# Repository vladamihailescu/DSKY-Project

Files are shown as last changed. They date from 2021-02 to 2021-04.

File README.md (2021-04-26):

# DSKY-Project
My open source journey to building a functional, historically-accurate DSKY interface that can be used in simulation. 
 
## v1.0 Hardware (Completed)
 - Raspberry Pi 3B+ running VirtualAGC + driving the display & keyboard
 - Nextion 4.3" LCD HMI (NX4827T043_11) display
 - Alarm Panel PCB designed by Riley Rainey
 - Hand assembled keyboard using Cherry MX blue key switches & Arduino UNO in USB HID mode
 - 3D Printed shell components made from models created/modified by Riley Rainey/Manoel DaSilva from original MIT drawings or myself

## v1.5 Hardware (In Progress)
 - Raspberry Pi 3B+ running VirtualAGC + driving the display & keyboard
 - Nextion 4.3" LCD HMI (NX4827T043_11) display
 - Alarm Panel PCB designed by Riley Rainey
 - Keyboard PCB designed by me with Cherry MX green key switches & LED backlighting
 - 3D Printed shell components made from models created/modified by Riley Rainey/Manoel DaSilva from original MIT drawings or myself

## v2.0 Hardware (Planned)
 - Raspberry Pi 3B+ running VirtualAGC + driving the display & keyboard
 - Custom EL display panel
 - Alarm Panel PCB designed by Riley Rainey
 - Keyboard switches assembled as per original spec using microswitches
 - 3D Printed shell components made from models created/modified by Riley Rainey from original MIT drawings or myself

## Software
 - Drivers for display, alarm panel & keyboard written in Python3
 - VirtualAGC project
 - Project Apollo - NASSP
 
## Setup
Raspberry Pi running VirtualAGC is driving the Nextion HMI, sending lamp instructions to the Alert board and reading keystrokes from Keyboard

## Task List
- 1.0
- [x] Build working GUI for HMI display
- [x] Driver for Nextion HMI display
- [x] Assemble alarm panel PCB
- [x] Driver for alarm panel
- [x] Assemble keyboard
- [x] Driver for keyboard
- [x] Update piDSKY2.py file
- [x] Test with VirtualAGC

- 1.5
- [x] Design & assemble a custom PCB for keyboard
- [ ] Improve code
- [ ] Refine GUI to more closely match original DSKY display
- [ ] Keyboard caps improvements
- [ ] Improve overall DSKY fit & finish & pave way to v2.0

## References
 [VirtualAGC Project](https://www.ibiblio.org/apollo/) - I am so thankful that this exists because it has been my dream to build my own DSKY ever since I first learned of the
 project\
 [Riley Rainey](https://github.com/rrainey) - His amazing work in designing the alert and keyboard PCBs, modeling the DSKY shell and inner components from original drawings gave
 me the opportunity to start this project\
 [Manoel DaSilva](https://github.com/ManoDaSilva) - He created the HMI file which I modified and adapted to my code and the Cherry MX keyswitch stems I used.\

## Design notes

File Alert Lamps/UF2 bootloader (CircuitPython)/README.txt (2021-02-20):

This UF2 bootloader is compiled for the Alarm Panel PCB designed by Riley Rainey (https://github.com/rrainey)
which uses the Microchip ATSAMD21E18A microcontroller.

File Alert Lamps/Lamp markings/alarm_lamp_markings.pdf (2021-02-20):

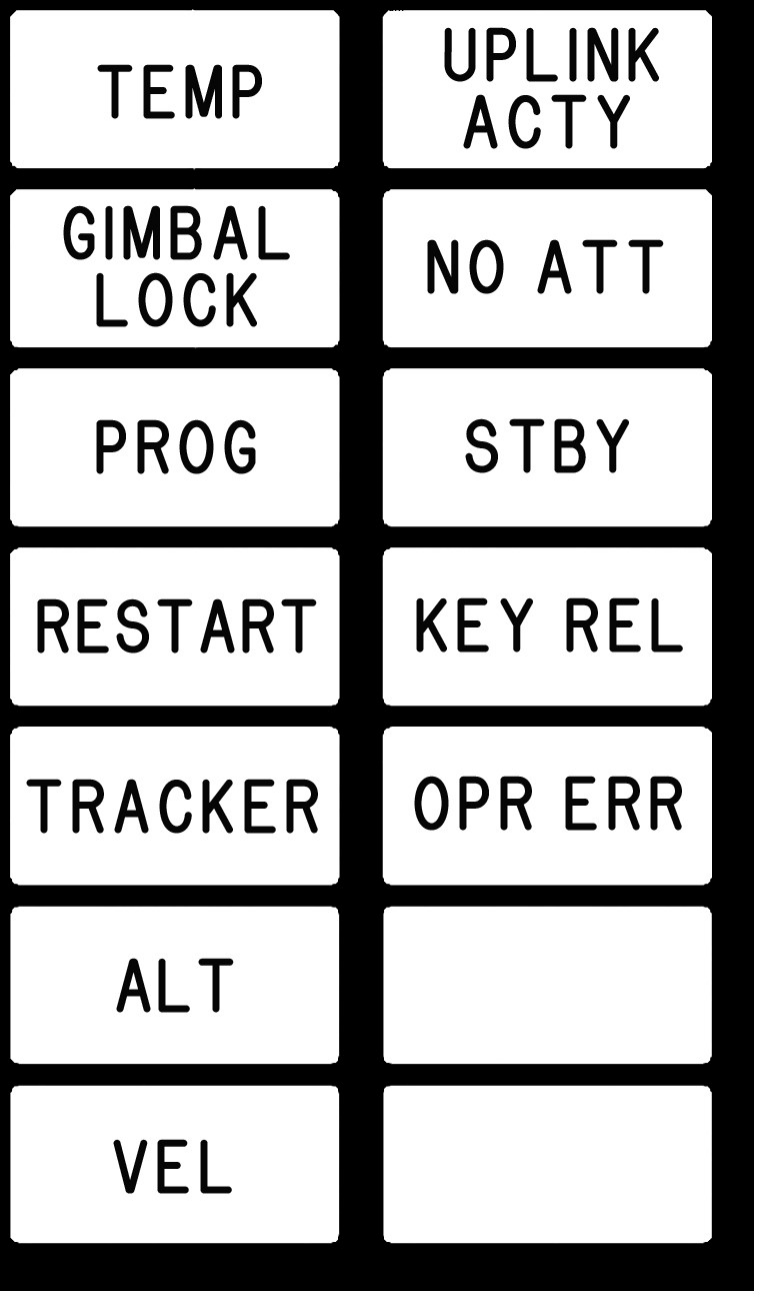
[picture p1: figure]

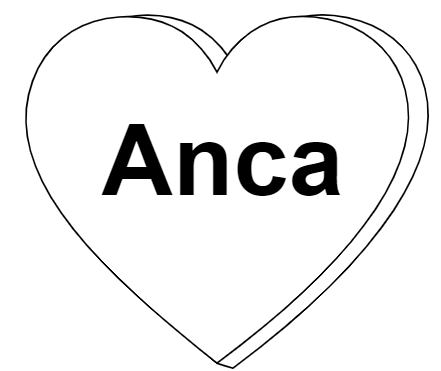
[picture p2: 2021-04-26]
Keyboard/PCB/DSKY_keyboard/anca_heart.png

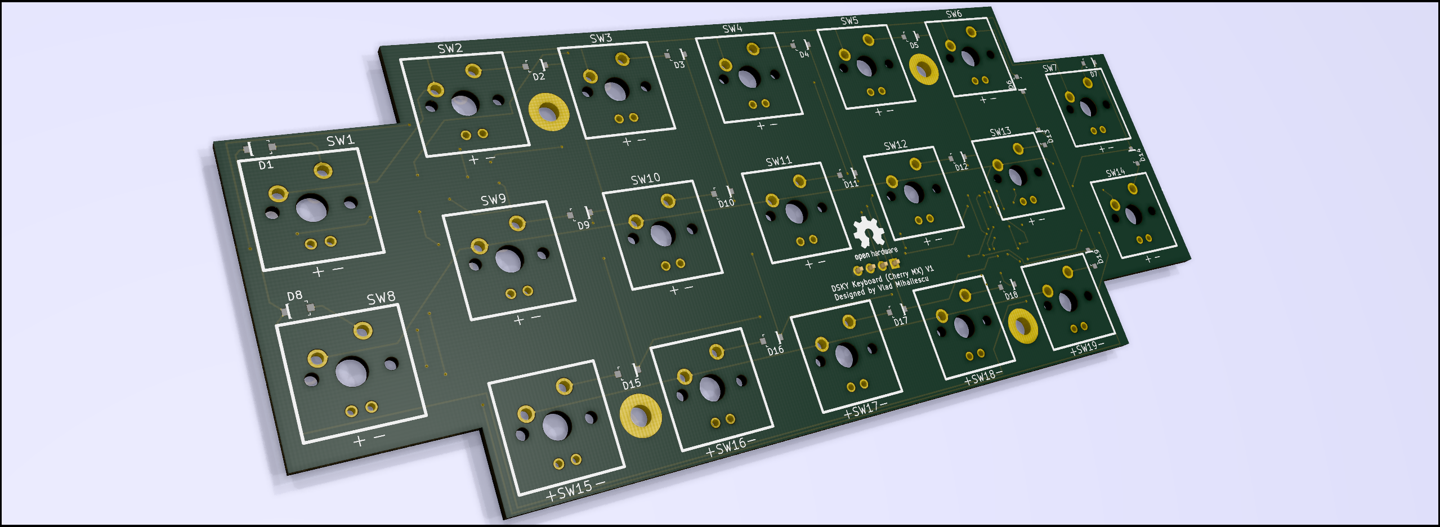
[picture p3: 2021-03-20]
Keyboard/PCB/DSKY_keyboard/DSKY_keyboard_Front.png

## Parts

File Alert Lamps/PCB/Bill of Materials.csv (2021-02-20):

Manufacturer Part Number | Manufacturer | Digi-Key Part Number | Packaging | Part Status | Quantity | Unit Price | Extended Price | Quantity Available | Mfg Std Lead Time | Description | RoHS Status | Lead Free Status | REACH Status
AQY232SZ | Panasonic Electric Works | 255-2690-1-ND | Cut Tape (CT) | Active | 15 | 4.481 | $67.21 | 7739 | 16 Weeks | SSR RELAY SPST-NO 500MA 0-60V | RoHS Compliant | Lead free | Not Available
CR0603-FX-1101ELF | Bourns Inc. | CR0603-FX-1101ELFCT-ND | Cut Tape (CT) | Active | 18 | 0.047 | $0.84 | 32367 | 14 Weeks | RES SMD 1.1K OHM 1% 1/10W 0603 | ROHS3 Compliant | Lead free | REACH Unaffected
1051330001 | Molex | WM9734CT-ND | Cut Tape (CT) | Active | 2 | 1.4 | $2.80 | 38785 | 13 Weeks | CONN RCPT USB2.0 MICRO B SMD | ROHS3 Compliant | Lead free | REACH Unaffected
AP2112K-3.3TRG1 | Diodes Incorporated | AP2112K-3.3TRG1DICT-ND | Cut Tape (CT) | Active | 4 | 0.72 | $2.88 | 0 | 30 Weeks | IC REG LINEAR 3.3V 600MA SOT25 | ROHS3 Compliant | Lead free | REACH Unaffected
7216 | Visual Communications Company - VCC | VCC7216-ND | Bulk | Not For New Designs | 45 | 1.046 | $47.07 | 2771 | 12 Weeks | LAMP INCAND T-1 WIRE TERM 5V | ROHS3 Compliant | Lead free | REACH Unaffected
CRGCQ0603F10K | TE Connectivity Passive Product | A129700CT-ND | Cut Tape (CT) | Active | 6 | 0.15 | $0.90 | 15229 | 19 Weeks | CRGCQ 0603 10K 1% | RoHS Compliant | Lead free | Not Available
CRGP0603F1K5 | TE Connectivity Passive Product | A130418CT-ND | Cut Tape (CT) | Active | 6 | 0.22 | $1.32 | 51357 | 19 Weeks | CRGP 0603 1K5 1% | RoHS Compliant | Lead free | Not Available
LT Q39G-Q1OO-25-1 | OSRAM Opto Semiconductors Inc. | 475-3442-1-ND | Cut Tape (CT) | Active | 2 | 0.57 | $1.14 | 46892 | 12 Weeks | LED GREEN DIFFUSED 0603 SMD | ROHS3 Compliant | Lead free | REACH Unaffected
LS Q976-NR-1 | OSRAM Opto Semiconductors Inc. | 475-2512-1-ND | Cut Tape (CT) | Active | 2 | 0.39 | $0.78 | 97330 | 12 Weeks | LED RED DIFFUSED 0603 SMD | ROHS3 Compliant | Lead free | REACH Unaffected
C0805C106K4PAC7210 | KEMET | 399-C0805C106K4PAC7210CT-ND | Cut Tape (CT) | Active | 6 | 0.28 | $1.68 | 7342 | 30 Weeks | CAP CER 10UF 16V X5R 0805 | ROHS3 Compliant | Not Available | REACH Unaffected
CL10A105KO8NNNC | Samsung Electro-Mechanics | 1276-1034-1-ND | Cut Tape (CT) | Active | 6 | 0.14 | $0.84 | 68766 | 22 Weeks | CAP CER 1UF 16V X5R 0603 | ROHS3 Compliant | Lead free | REACH Unaffected
KMR231NG LFS | C&K | CKN10246CT-ND | Cut Tape (CT) | Active | 2 | 0.8 | $1.60 | 14433 | 18 Weeks | SWITCH TACTILE SPST-NO 0.05A 32V | ROHS3 Compliant | Lead free | REACH Unaffected
ATSAMD21E18A-MU | Microchip Technology | ATSAMD21E18A-MU-ND | Tray | Active | 2 | 4.85 | $9.70 | 850 | 35 Weeks | IC MCU 32BIT 256KB FLASH 32QFN | ROHS3 Compliant | Lead free | REACH Unaffected
CR0603-FX-1501ELF | Bourns Inc. | 118-CR0603-FX-1501ELFCT-ND | Cut Tape (CT) | Active | 4 | 0.15 | $0.60 | 2301 | 14 Weeks | RES SMD 1.5K OHM 1% 1/10W 0603 | ROHS3 Compliant | Lead free | REACH Unaffected
This list includes plenty of spares and only adds a few extra dollars to the total price but worth it in case you mess up/lose parts.

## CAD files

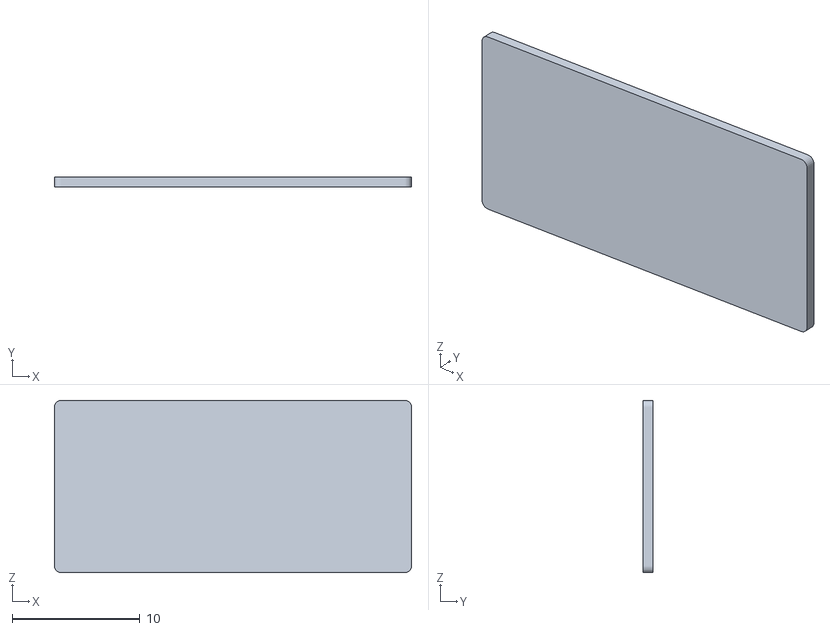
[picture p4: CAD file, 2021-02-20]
Alert Lamps/Lamp markings/Translucent inserts tree v4 v1.stl
27.9 x 0.762 x 13.5

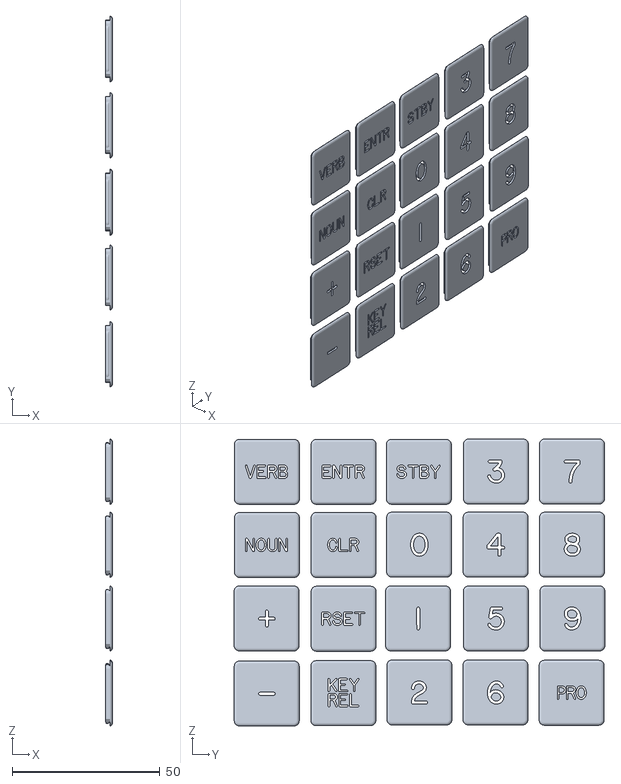
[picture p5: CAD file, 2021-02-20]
Keyboard/Keycaps/Markings/DSKY_KEYCAP v5.stl
2.29 x 125.3 x 97.0

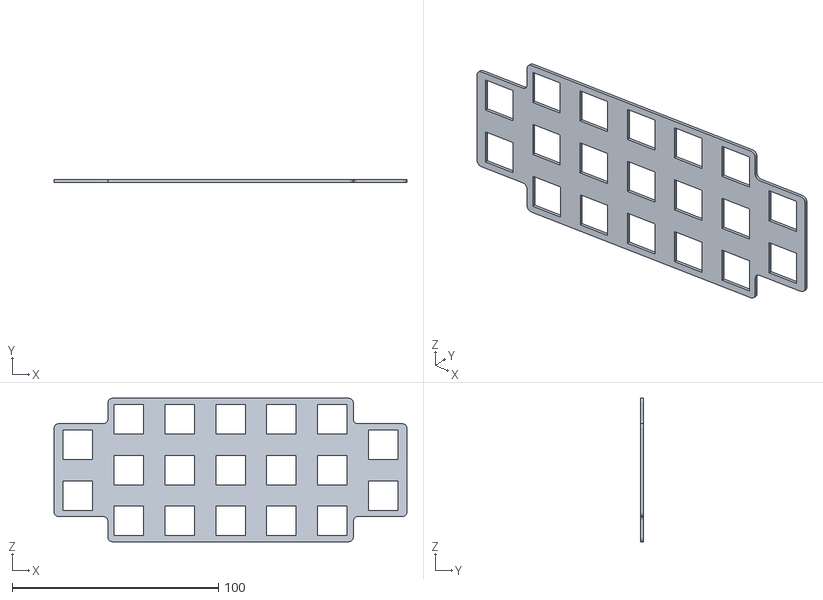
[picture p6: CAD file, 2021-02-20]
Keyboard/STL files/cherrymx_panel_mount.stl
171.0 x 1.30 x 69.6

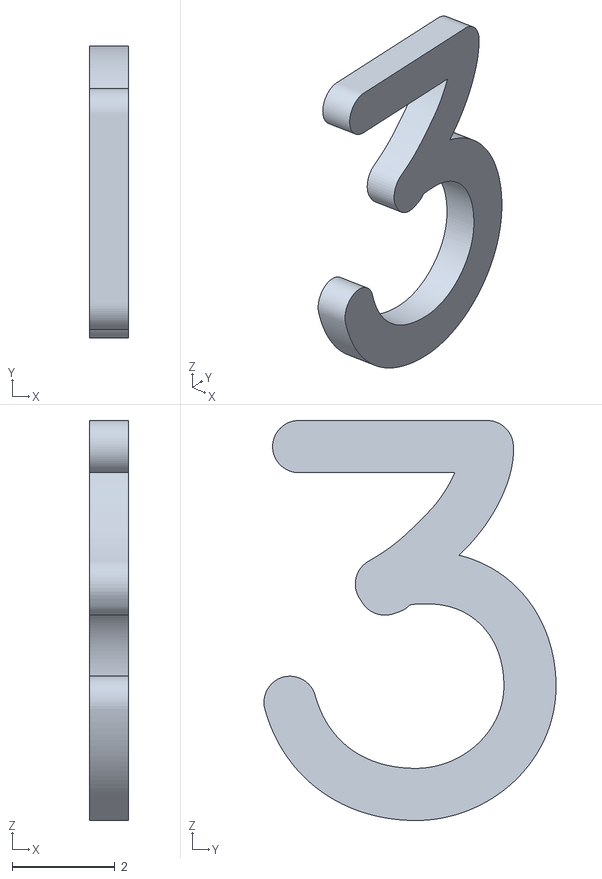
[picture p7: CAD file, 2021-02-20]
Keyboard/Keycaps/Markings/LP_3.stl
0.762 x 5.69 x 7.79

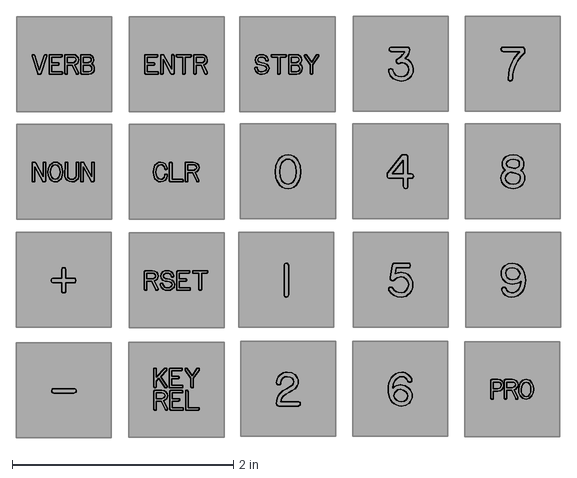
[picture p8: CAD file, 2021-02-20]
Keyboard/Keycaps/Markings/DSKY-keycaps.dxf
4.93 x 3.81 in

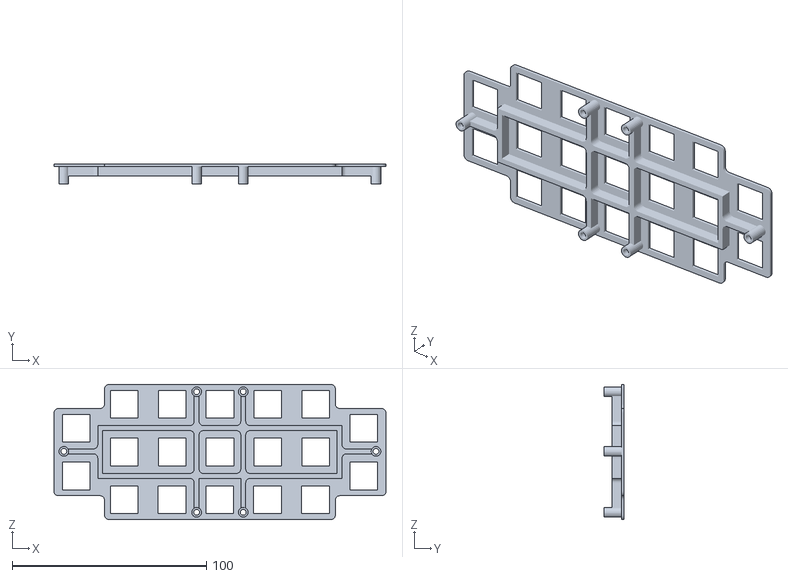
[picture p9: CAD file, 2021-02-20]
Keyboard/STL files/2004968E-ModFor3DPrint_VLAD v2.stl
171.0 x 10.3 x 69.6

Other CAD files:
Keyboard/CAD files/DSKY_keyboard_layout.dwg
Keyboard/Keycaps/Markings/verb.dxf
Alert Lamps/Lamp markings/Translucent inserts tree v4 v0.f3d

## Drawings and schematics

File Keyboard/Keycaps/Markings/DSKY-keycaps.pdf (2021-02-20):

3
7

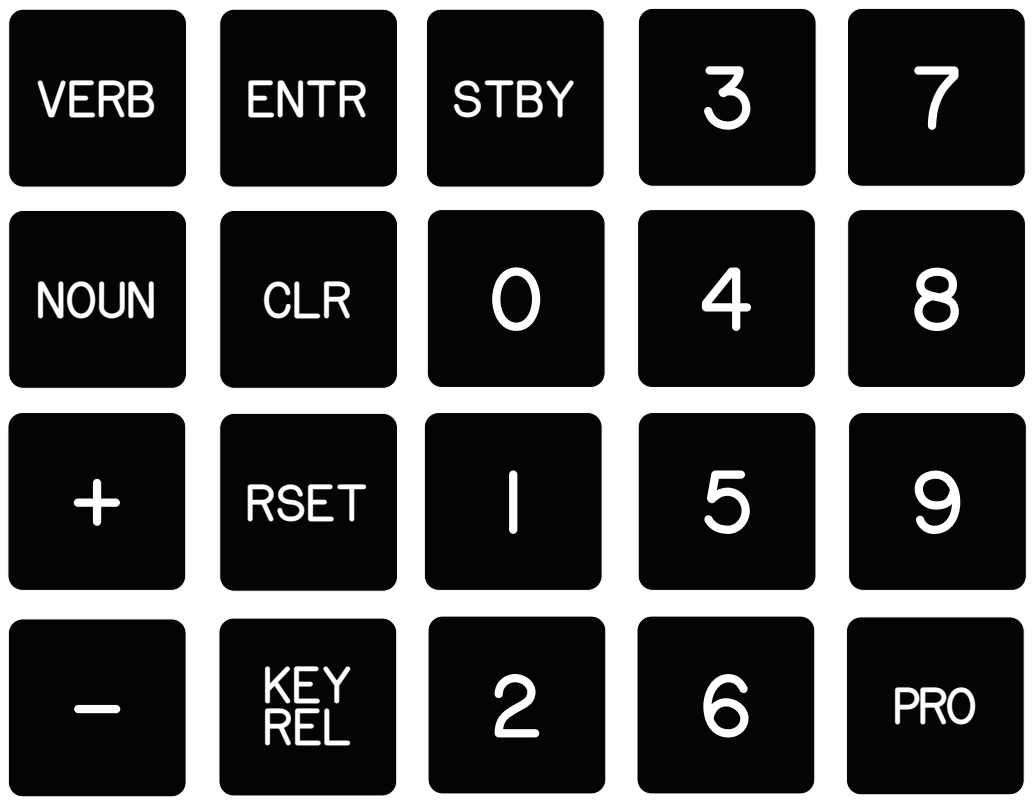
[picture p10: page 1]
VERB; NOUN; ENTR; CLR; RSET; KEY REL; STBY; PRO

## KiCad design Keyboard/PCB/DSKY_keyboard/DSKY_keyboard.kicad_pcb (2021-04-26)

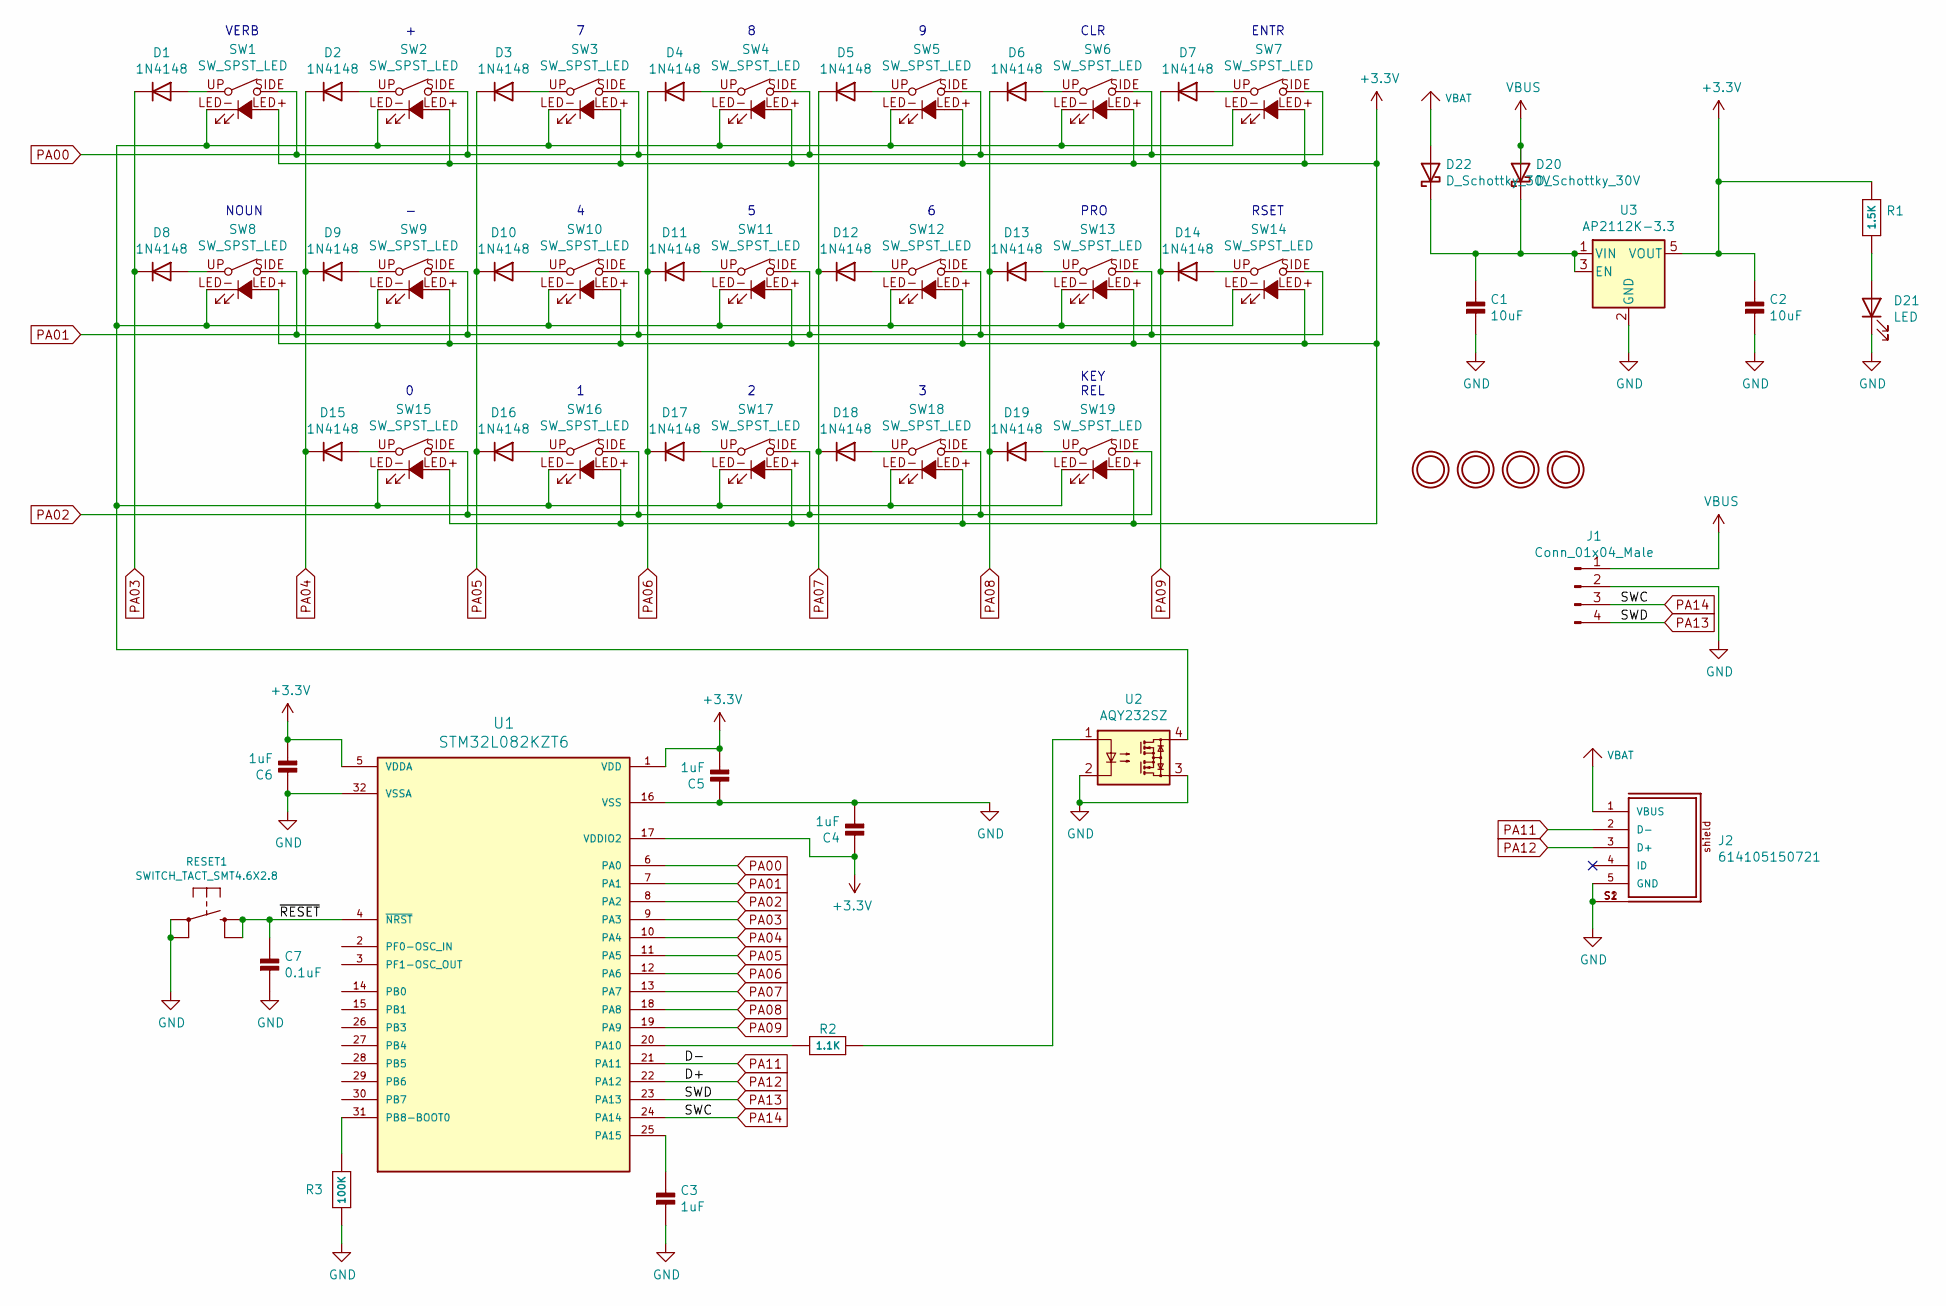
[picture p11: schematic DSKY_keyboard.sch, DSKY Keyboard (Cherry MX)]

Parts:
C1, C2: 10uF; 0805-NO
C3, C4, C5, C6: 1uF; 0603-NO
C7: 0.1uF; 0603-NO
D1, D2, D3, D4, D5, D6, D7, D8, D9, D10, D11, D12, D13, D14, D15, D16, D17, D18, D19: 1N4148; SOD-123
D20, D22: D_Schottky_30V; SOD-123FL
D21: LED; CHIPLED_0603_NOOUTLINE
J1: Conn_01x04_Male; PinHeader_1x04_P2.54mm_Horizontal
J2: 614105150721; PART-NUMBER 614105150721
J3, J4, J5, J6: MOUNTINGHOLE3.0; MOUNTINGHOLE_2.0_PLATED
R1: 1.5K; 0603-NO
R2: 1.1K; 0603-NO
R3: 100K; 0603-NO
RESET1: SWITCH_TACT_SMT4.6X2.8; BTN_KMR2_4.6X2.8
SW1, SW2, SW3, SW4, SW5, SW6, SW7, SW8, SW9, SW10, SW11, SW12, SW13, SW14, SW15, SW16, SW17, SW18, SW19: SW_SPST_LED; CHERRYMX-NN-LED
U1: STM32L082KZT6; STM32F042K6T6
U2: AQY232SZ; SO-4_4.4x4.3mm_P2.54mm
U3: AP2112K-3.3; SOT23-5

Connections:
+3V3: C2.1, C4.1, C5.2, C6.2, R1.1, SW1.LED+, SW2.LED+, SW3.LED+, SW4.LED+, SW5.LED+, SW6.LED+, SW7.LED+, SW8.LED+, SW9.LED+, SW10.LED+, SW11.LED+, SW12.LED+, SW13.LED+, SW14.LED+, SW15.LED+, SW16.LED+, SW17.LED+, SW18.LED+, SW19.LED+, U1.1 (VDD), U1.5 (VDDA), U1.17 (VDDIO2), U3.5 (VOUT)
/~RESET: C7.1, RESET1.B (S), RESET1.B' (S1), U1.4 (~NRST)
GND: C1.2, C2.2, C3.2, C4.2, C5.1, C6.1, C7.2, D21.1 (K), J1.2, J2.5 (GND), J2.S1, J2.S2, R3.1, RESET1.A, RESET1.A' (P1), U1.16 (VSS), U1.32 (VSSA), U2.2, U2.3, U3.2 (GND)
unnamed: C1.1, D20.1 (K), D22.1 (K), U3.1 (VIN), U3.3 (EN)
unnamed: C3.1, U1.25 (PA15)
unnamed: D1.2 (A), SW1.UP
unnamed: D2.2 (A), SW2.UP
unnamed: D3.2 (A), SW3.UP
unnamed: D4.2 (A), SW4.UP
unnamed: D5.2 (A), SW5.UP
unnamed: D6.2 (A), SW6.UP
unnamed: D7.2 (A), SW7.UP
unnamed: D8.2 (A), SW8.UP
unnamed: D9.2 (A), SW9.UP
unnamed: D10.2 (A), SW10.UP
unnamed: D11.2 (A), SW11.UP
unnamed: D12.2 (A), SW12.UP
unnamed: D13.2 (A), SW13.UP
unnamed: D14.2 (A), SW14.UP
unnamed: D15.2 (A), SW15.UP
unnamed: D16.2 (A), SW16.UP
unnamed: D17.2 (A), SW17.UP
unnamed: D18.2 (A), SW18.UP
unnamed: D19.2 (A), SW19.UP
unnamed: D21.2 (A), R1.2
unnamed: R2.1, U2.1
unnamed: R2.2, U1.20 (PA10)
unnamed: R3.2, U1.31 (PB8-BOOT0)
unnamed: SW1.LED-, SW2.LED-, SW3.LED-, SW4.LED-, SW5.LED-, SW6.LED-, SW7.LED-, SW8.LED-, SW9.LED-, SW10.LED-, SW11.LED-, SW12.LED-, SW13.LED-, SW14.LED-, SW15.LED-, SW16.LED-, SW17.LED-, SW18.LED-, SW19.LED-, U2.4
PA00: SW1.SIDE, SW2.SIDE, SW3.SIDE, SW4.SIDE, SW5.SIDE, SW6.SIDE, SW7.SIDE, U1.6 (PA0)
PA01: SW8.SIDE, SW9.SIDE, SW10.SIDE, SW11.SIDE, SW12.SIDE, SW13.SIDE, SW14.SIDE, U1.7 (PA1)
PA02: SW15.SIDE, SW16.SIDE, SW17.SIDE, SW18.SIDE, SW19.SIDE, U1.8 (PA2)
PA03: D1.1 (K), D8.1 (K), U1.9 (PA3)
PA04: D2.1 (K), D9.1 (K), D15.1 (K), U1.10 (PA4)
PA05: D3.1 (K), D10.1 (K), D16.1 (K), U1.11 (PA5)
PA06: D4.1 (K), D11.1 (K), D17.1 (K), U1.12 (PA6)
PA07: D5.1 (K), D12.1 (K), D18.1 (K), U1.13 (PA7)
PA08: D6.1 (K), D13.1 (K), D19.1 (K), U1.18 (PA8)
PA09: D7.1 (K), D14.1 (K), U1.19 (PA9)
PA11: J2.2 (D-), U1.21 (PA11)
PA12: J2.3 (D+), U1.22 (PA12)
PA13: J1.4, U1.23 (PA13)
PA14: J1.3, U1.24 (PA14)
VBAT: D22.2 (A), J2.1 (VBUS)
VBUS: D20.2 (A), J1.1

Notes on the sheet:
RSET
CLR
ENTR
KEY REL
PRO
NOUN
VERB

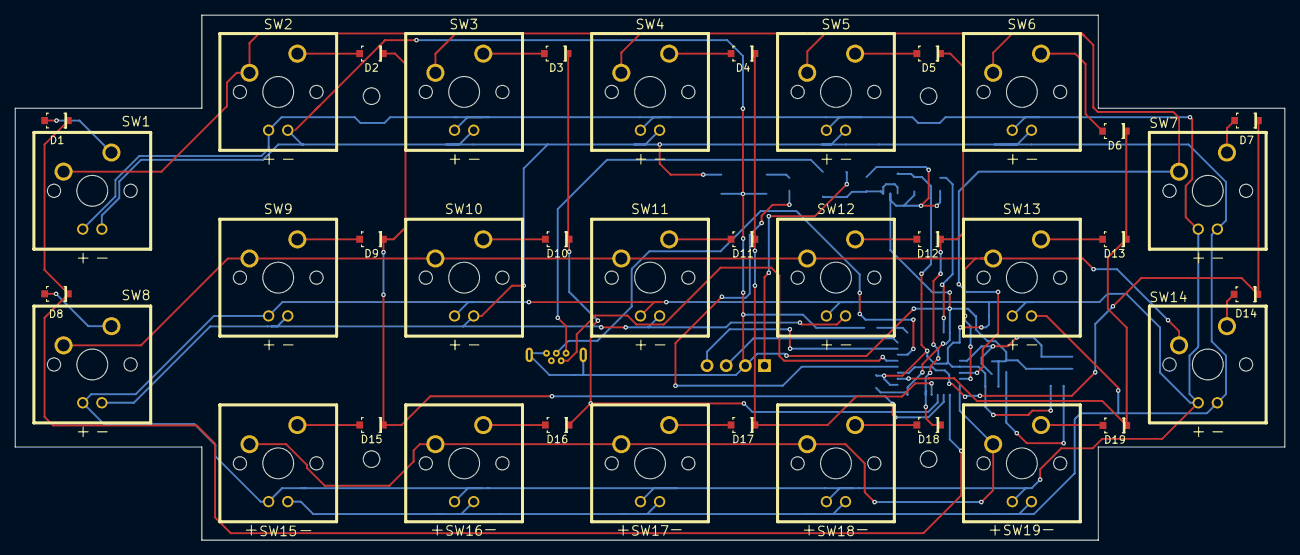
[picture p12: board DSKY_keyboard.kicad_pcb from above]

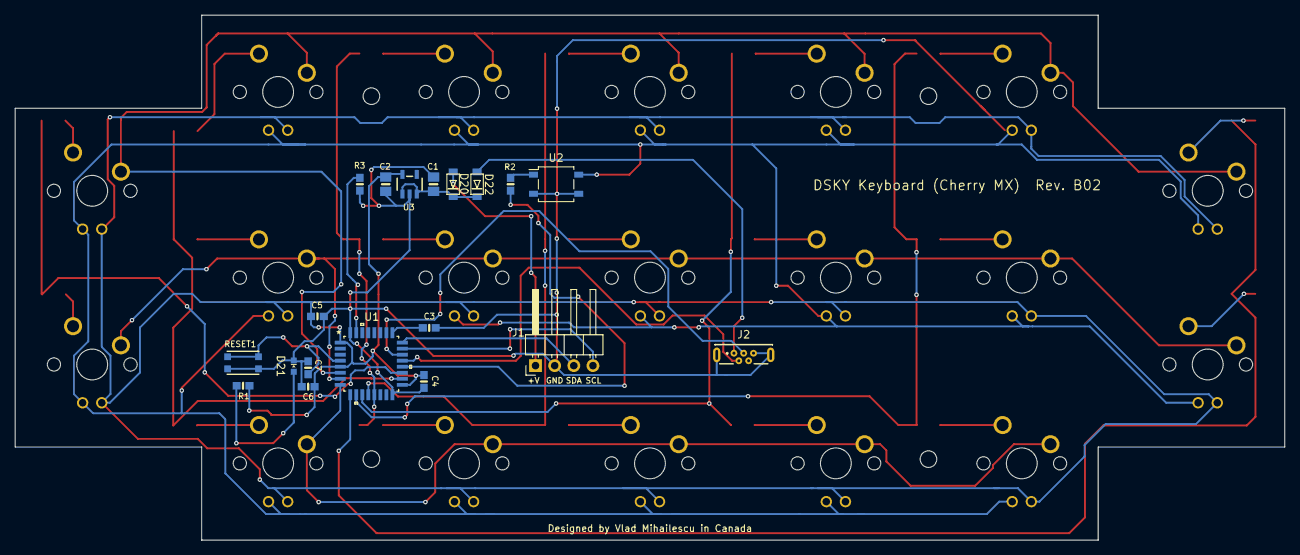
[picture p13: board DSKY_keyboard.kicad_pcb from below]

Board: 2 copper layers, 168.4 x 69.6 mm, 57 parts (19 on the bottom side), 45 nets.

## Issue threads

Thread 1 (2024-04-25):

Attempting to run piDSKY2.py, and receive errors

TheRealGreatOldOne, 2024-04-25:
Hi

I'm trying to get your DSKY code running on a pi3B+ with a Nextion display. I have the HMI compiled and the resulting TFT file flashed to the screen. On power up, I get the Apollo project logo.

When trying to run  piDSKY2.py (I have modified to point to the serial port I'm using for the Nextion, and a spare that's not connected to anything right now for the lights), I get the following message:

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

Which display is this referring to? The Nextion? Isn't that just a serial connection that is already defined? I'm confused as to what this is asking for.

Can you help at all? Thanks,

Jason

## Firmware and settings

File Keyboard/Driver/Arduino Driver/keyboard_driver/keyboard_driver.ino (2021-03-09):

/* Copyright (c) 2021 - Vlad Mihailescu
 * Permission is hereby granted, free of charge, to any person obtaining a copy
 * of this software and associated documentation files (the "Software"), to deal
 * in the Software without restriction, including without limitation the rights
 * to use, copy, modify, merge, publish, distribute, sublicense, and/or sell
 * copies of the Software, and to permit persons to whom the Software is
 * furnished to do so, subject to the following conditions:
 * The above copyright notice and this permission notice shall be included in all
 * copies or substantial portions of the Software.
 * THE SOFTWARE IS PROVIDED "AS IS", WITHOUT WARRANTY OF ANY KIND, EXPRESS OR
 * IMPLIED, INCLUDING BUT NOT LIMITED TO THE WARRANTIES OF MERCHANTABILITY,
 * FITNESS FOR A PARTICULAR PURPOSE AND NONINFRINGEMENT. IN NO EVENT SHALL THE
 * AUTHORS OR COPYRIGHT HOLDERS BE LIABLE FOR ANY CLAIM, DAMAGES OR OTHER
 * LIABILITY, WHETHER IN AN ACTION OF CONTRACT, TORT OR OTHERWISE, ARISING FROM,
 * OUT OF OR IN CONNECTION WITH THE SOFTWARE OR THE USE OR OTHER DEALINGS IN THE
 * SOFTWARE.
*/

#include <Keypad.h>

const byte ROWS = 3; 
const byte COLS = 7; 

uint8_t buf[8] = {0};

char hexaKeys[ROWS][COLS] = {
  {87, 87, 36, 37, 38, 6, 8},
  {25, 86, 33, 34, 35, 19, 21},
  {17, 39, 30, 31, 32, 14}
};

byte rowPins[ROWS] = {2, 3, 4}; 
byte colPins[COLS] = {5, 6, 7, 8, 9, 10, 11}; 

Keypad dsKb = Keypad(makeKeymap(hexaKeys), rowPins, colPins, ROWS, COLS); 

void setup(){
  Serial.begin(9600);
}
  
void loop(){
  char dsKey = dsKb.getKey();
  
  if (dsKey){
    buf[2] = dsKey;
    Serial.write(buf, 8);
    releaseKey();
  }
}

void releaseKey()
{
  buf[0] = 0;
  buf[2] = 0;
  Serial.write(buf, 8);  // Release key  
}

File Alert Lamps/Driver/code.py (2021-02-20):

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
import board
import busio
import digitalio

uart = busio.UART(board.TX, board.RX, baudrate=115200)

# Dict of CLI parameters and corresponding lamp
lamps = {'3': digitalio.DigitalInOut(board.D1),    # UPLINK ACTY
         '2': digitalio.DigitalInOut(board.D8),    # TEMP
         '5': digitalio.DigitalInOut(board.D5),    # NO ATT
         '4': digitalio.DigitalInOut(board.D9),    # GIMBAL LOCK
         '7': digitalio.DigitalInOut(board.D6),    # STBY
         '6': digitalio.DigitalInOut(board.D10),   # PROG
         'B': digitalio.DigitalInOut(board.D7),    # KEY REL
         '8': digitalio.DigitalInOut(board.D11),   # RESTART
         '9': digitalio.DigitalInOut(board.D16),   # OPER ERR
         'A': digitalio.DigitalInOut(board.D12),   # TRACKER
         'D': digitalio.DigitalInOut(board.D17),   # PRIO DSP
         'RED': digitalio.DigitalInOut(board.D13), # On-board LED
         'C': digitalio.DigitalInOut(board.D14),   # ALT
         'F': digitalio.DigitalInOut(board.D18),   # NO DAP
         'E': digitalio.DigitalInOut(board.D15)}   # VEL

for i in lamps:
    lamps[i].direction = digitalio.Direction.OUTPUT

lastLampState = []

while True:
    data_rcvd = uart.read(14)
    if data_rcvd is not None:
        lamps['RED'].value = True # Blink on-board LED during RX
        data = ''.join([chr(i) for i in data_rcvd])
        # Remove unwanted characters from data string
        for ch in ['G','H','I','J','K','L','M','N','O','P','Q','R','S','T','U','V','W','X','x','Y','Z','a','b']:
            if ch in data:
                data = data.replace(ch,'')
        data = list(data)

        if data != '':
        # if lamp code was not present in last state, turn it ON
            lastLampsON = []
            for i in range(0, len(data)):
                lastLampsON += data[i]
                if data[i] not in lastLampState:
                    lamps[data[i]].value = True
                # If lamp code present in last state, it's already on so do nothing
                else:
                    pass
            for i in range(0, len(lastLampState)):
                # Turn OFF lamps that were previously ON unless already OFF
                if lastLampState[i] not in data:
                    lamps[lastLampState[i]].value = False
        elif data == '':
            for i in lastLampsON:
                lamps[lastLampsON[i]].value = False
        lastLampState = data
        lamps['RED'].value = False

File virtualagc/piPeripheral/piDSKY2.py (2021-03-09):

#!/usr/bin/python3
# Copyright 2017 Ronald S. Burkey
# 
# This file is part of yaAGC.
# 
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
# Filename: 	piDSKY2.py
# Purpose:	This is a variation of piDSKY.py (a "generic" DSKY
#		simulation for use with yaAGC) that is targeted for
#		a Raspberry Pi using a specific hardware model, and
#		is not really applicable for any other purpose.
# Reference:	http://www.ibiblio.org/apollo/developer.html
# Mod history:	2021-02-17 Added functionality for driving a  
#				Nextion 4.3" display and custom alarm panel board.
#       2017-11-19 RSB	Began adapting from piDSKY.py.
#		2017-11-20 RSB	Added command-line arguments of various
#				kinds and fixed the keyboard binding
#				in the tkinter window.  Systematized
#				the widget positioning to just a few
#				variables rather than hardcoding them
#				lots of places.
#		2017-11-21 RSB	Changed PRO timeout from 0.25 to 0.5.
#		2017-11-22 RSB	Graphical rendering of widgets now made
#				lazy, so that they're not drawn at all
#				if they haven't changed.
#		2017-11-24 RSB	Added suggested stuff for numeric keypad.
#		2017-11-25 RSB	Added indicator-lamp controls based on
#				the external program 'led-panel', and 
#				duplicated (I hope) Mike Stewart's fixes
#				to yaDSKY2 a year or so ago, for the
#				RESTART, STANDBY, OPR ERR, and KEY REL
#				lamps.  For the STANDBY behavior to 
#				work properly, also changed the PRO
#				timeout to 0.75.  (Needed to be in the
#				range 0.64 to 1.92.)
#		2017-11-26 RSB	Added timing filters to prevent the led-panel
#				from being run when it is already running.
#				My dummy version of led-panel has been 
#				modified (to test this feature) to always
#				take around a second to run, and to include
#				a high-resolution time in its display message.
#				Fixed dumb bugs in TEMP, VEL, and UPLINK lamps.
#				Now expects key-repeat to be off, and detects
#				release of the PRO key directly.
#		2017-11-27 RSB	At Sam's request, emptied out the default 
#				command-string for led-panel (to eliminate,
#				apparently, the backlights for the keypad).
#				Added vncserverui detection.  Swapped the
#				BackSpace and Tab aliases (now for PRO and
#				KEY REL), so as to be able to implement a
#				key-release for the PRO alias.  The 
#				RRRRR exit had ceased working and, as far
#				as I can tell, should never have worked in
#				the first place.
#		2017-11-28 RSB	Replaced the single-character global buffers
#				I was using for buffering GUI keypresses
#				and releases with a proper queue that insures
#				no presses or releases are lost and that they
#				are all processed in the correct order.
#				Added some instrumentation that keeps a count
#				of all uses of V35E and prints them out on
#				stderr. Added code to catch exceptions in use
#				of psutil (that I think can happen when trying
#				to get the attributes of a process which has
#				just disappeared).
#		2017-11-29 RSB	Initial attempt at coding up a PIGPIO-based
#				solution for running the indicator lamps,
#				vs using the external program 'led-panel'.
#				The logic is "complete", but I don't have any
#				of the technical documentation for the LED
#				board and don't recall the part number of the
#				driver chip :-), so it's pretty much guaranteed
#				not to work as-is.  Nevertheless, stuff like
#				the SPI API can be checked out to a certain
#				degree.
#		2017-12-04 RSB	Fixed PIGPIO control of lamps, I think.
#		2017-12-06 RSB	Added 3 dots.
#		2017-12-09 RSB	Added --record and --playback.  Cleaned up
#				the record-keeping about the last values of
#				the input channels a lot, so that a lot of
#				unnecessary duplication of operations is 
#				presumably prevented.
#		2017-12-11 RSB	Now accepts floats as timestamps in playback
#				files, though hopefully that will never occur.
#		2017-12-12 RSB	Added AGC input channels (i.e., keystrokes) to
#				the --record and --playback features.  What I
#				intend to do with them in playback is to flash
#				the backlight on the associated keys momentarily,
#				but I don't have enough technical information to
#				do so, nor is it wired up on the DSKY I have yet,
#				so at the moment it does nothing in playback other
#				than hook it.
#		2017-12-13 RSB	Added the key-backlight on playback feature I 
#				simply hooked yesterday.  There was a bug in 
#				keeping track of which lamps had changed, that
#				became apparently only in adding an 8th digit
#				for the LED controller.
#		2017-12-16 RSB	Now allow AGC-connect operation to timeout
#				(currently 10 seconds).  Useful for connection
#				to yaAGC external to Pi.
#		2017-12-20 RSB	Added --lamptest.
#		2017-12-21 RSB	Added --manual.
#		2017-12-27 RSB	The SPI handle wasn't getting released in under
#				some circumstances when the program exited,
#				causing re-runs to eventually fail when no
#				more SPI handles were available in PIGPIOD.
#				I hope I tracked all those down and fixed them.
#		2017-12-28 RSB	Added a little extra (probably unnecessary) code
#				to insure shutdown of PIGPIO on termination.
#				Tests of yesterday's SPI-shutdown code have been
#				working fine, though.
#		2017-12-30 RSB	Allowed corrupted lines in playback scripts, 
#				in order to handle comment lines.
#		2017-12-31 RSB	Modified the playback scripts in two ways:  First,
#				it explicitly checks for '#...' and removes them
#				as being comments, and doesn't simply rely on 
#				the line being ill-formed.  Secondly, after 
#				removal of comments, any line NOT of the form
#				"float octal octal" is treated as "float command",
#				where the command is executed in the background
#				by shelling out.  Thus, arbitrary BASH commands such
#				as audio playback can be put into the script.
#		2018-01-06 MAS	Switched the TEMP light to use channel 163 instead
#				of channel 11.
#		2018-03-10 RSB	Added --gunmetal option.
#
# About the design of this program ... yes, a real Python developer would 
# objectify it and have lots and lots of individual modules defining the objects.
# However, I'm not a real Python developer, and this is simply one stand-alone
# file comprising all of the functionality.  In other words, I don't see that
# any of this code is particularly reusable, so I haven't bothered to attempt to
# encapsulate it into reusable modules.
#
# In this hardware model:
#
#    1.	yaAGC and piDSKY2.py are running on a Raspberry Pi, using the
#	Raspbian operating system.
#    2. There is a physical model of a DSKY, accessible via the Pi's GPIO.
#    3. The physical DSKY's keyboard is accessed as a normal keyboard (as
#	far as Raspbian is concerned) that provides the usual keycodes
#	(0 1 2 3 4 5 6 7 8 9 + - V N C P K R Enter) when the physical DSKY's
#	buttons are pressed.  Additionally, there are some keycode aliases
#	for the keycodes just mentioned, which can be used if alternate physical
#	keypads are used.
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

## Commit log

2021-02-20 Added new/updated files
    [2004968E-ModFor3DPrint_VLAD v2.stl, Bill of Materials.csv, DSKY-keycaps.dxf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]
2021-03-20 Added keyboard PCB files
    [DSKY_keyboard-B_Cu.gbr, DSKY_keyboard-B_Mask.gbr, DSKY_keyboard-B_Paste.gbr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]
2021-03-20 Updated PCB
    [DSKY_keyboard.kicad_pcb]
2021-03-23 PCB updates
    [DSKY_keyboard-B_Cu.gbr, DSKY_keyboard-B_Mask.gbr, DSKY_keyboard-B_Paste.gbr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]

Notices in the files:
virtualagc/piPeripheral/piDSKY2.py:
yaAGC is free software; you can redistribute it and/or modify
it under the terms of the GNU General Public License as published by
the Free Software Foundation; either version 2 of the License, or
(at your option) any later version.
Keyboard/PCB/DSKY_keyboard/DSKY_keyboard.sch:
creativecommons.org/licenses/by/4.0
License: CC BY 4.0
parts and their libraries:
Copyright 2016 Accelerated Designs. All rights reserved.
